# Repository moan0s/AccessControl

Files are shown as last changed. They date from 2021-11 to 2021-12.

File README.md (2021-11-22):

# AccessControl
To control asual key box with an ESP over the cloud in the fablab of my university. As a server ILMO (https://github.com/moan0s/ILMO) is used.
For the usage of the key tresor from wuerth it is neccesarry to modify it a bit. You have to remove the nose and replace it by the electromagnetic lock drawer. Also the locker pin at the door has to be replaced by the printed version.

The printed box covers the whole electronic stuff and also two LEDs and the RFID modul.

The circuit is made with fritzing. (https://fritzing.org/)
The 3d parts are made with Solid Works Student.

Bill of materials:
* RC552 (RFID Reader)
* ESP32
* Electromagnetic Lock Drawer (e.g. https://www.amazon.de/gp/product/B08G58WZDQ/ref=ppx_yo_dt_b_asin_title_o02_s00?ie=UTF8&psc=1)
* Key tresor (e.g. https://eshop.wuerth.de/Haengeschrank-zur-Schluesselaufbewahrung-SHSLSHRNK-METALL-22-SCHLUESSEL/0824010080.sku/de/DE/EUR/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)
* Some small electronic components (see Circuit diagram)
* M4 Screws, washers and nuts

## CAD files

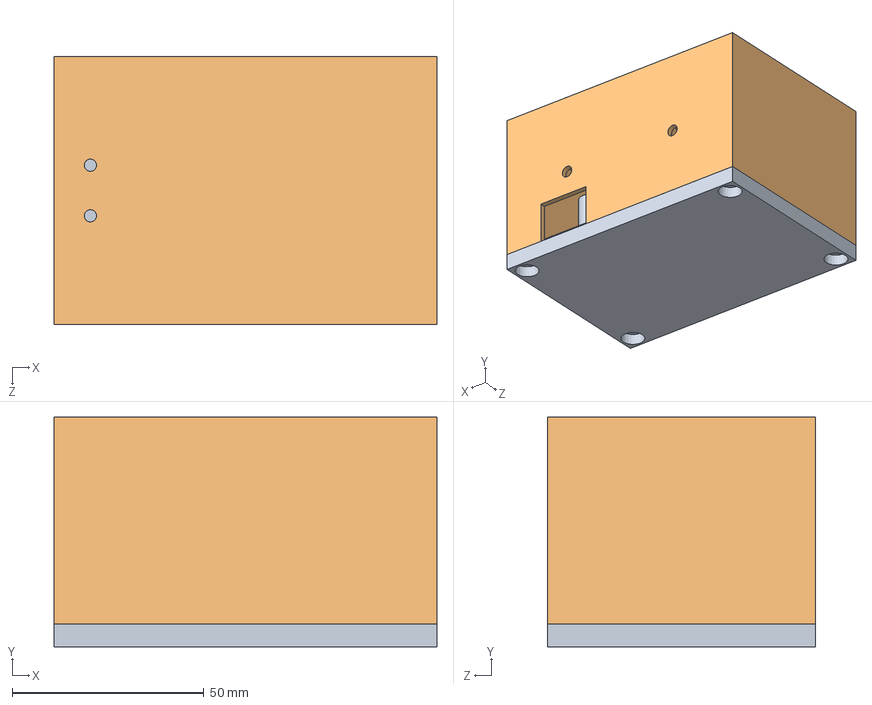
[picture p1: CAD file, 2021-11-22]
CAD/Solid Works/CaseComplete.SLDASM
100.0 x 60.0 x 70.0 mm
CaseTop
CaseBottom

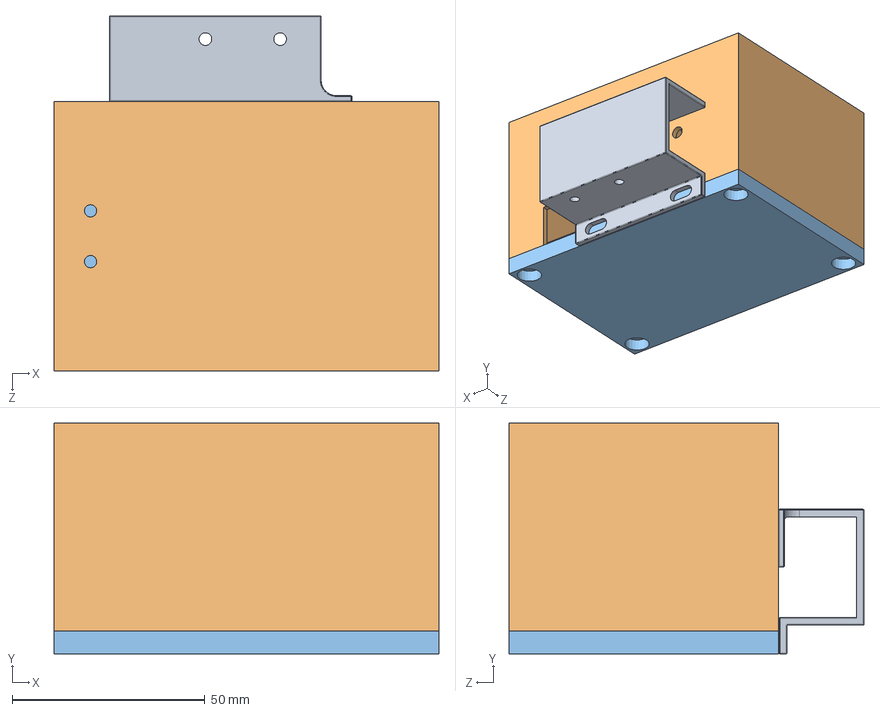
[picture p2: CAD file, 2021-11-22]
CAD/Solid Works/Complete.SLDASM
100.0 x 60.0 x 92.2 mm
DrawerHolder
CaseTop
CaseBottom

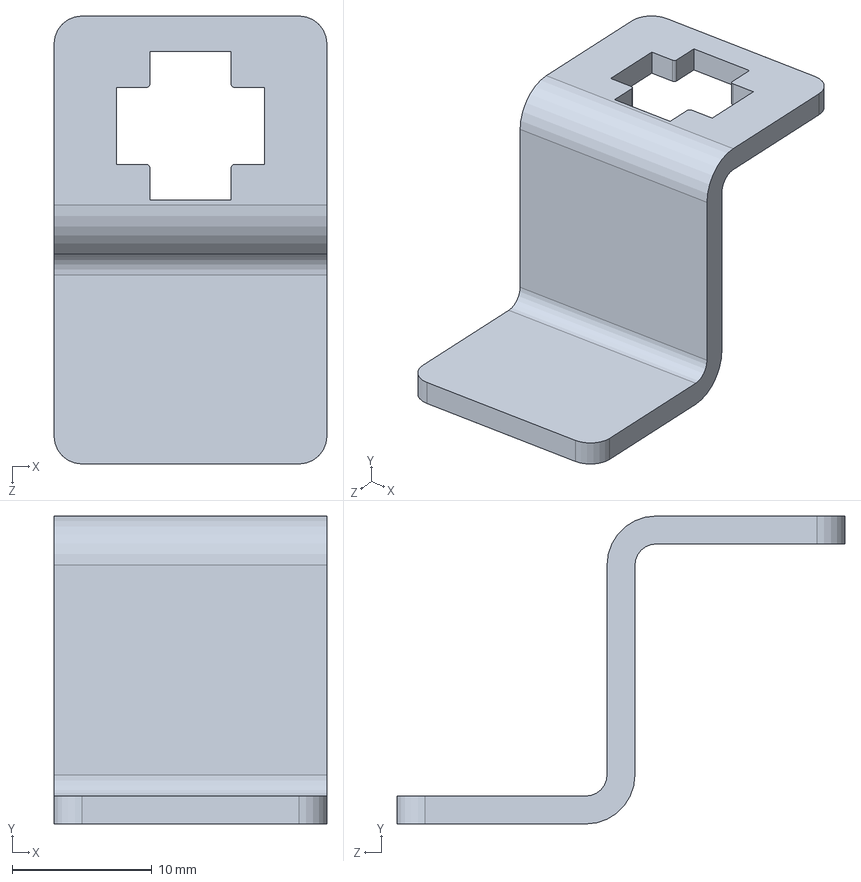
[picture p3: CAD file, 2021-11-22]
CAD/Solid Works/LockerPin.SLDPRT
19.5 x 22.0 x 32.0 mm

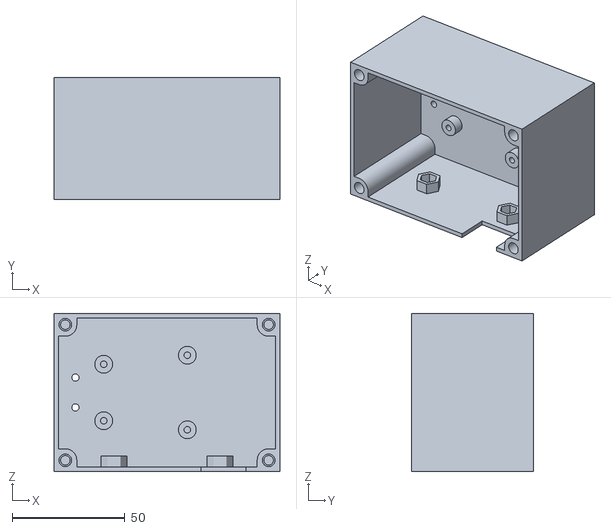
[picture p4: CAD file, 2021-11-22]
CAD/STL/CaseTop.STL
100.0 x 54.0 x 70.0

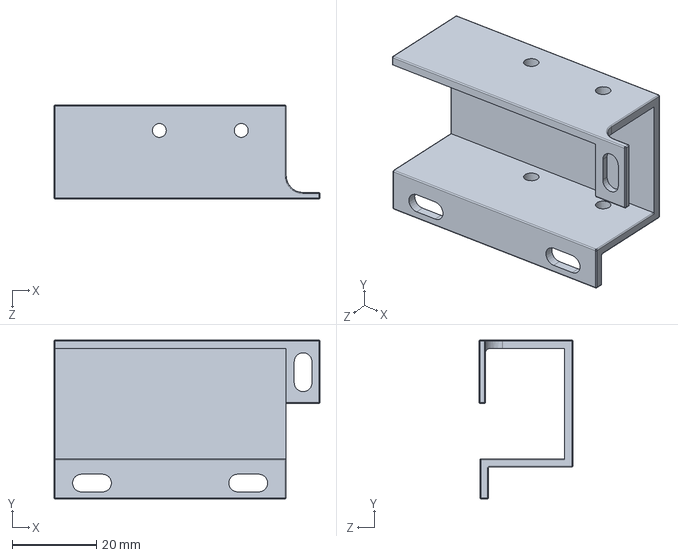
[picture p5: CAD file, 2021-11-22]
CAD/Solid Works/DrawerHolder.SLDPRT
63.0 x 37.6 x 22.2 mm

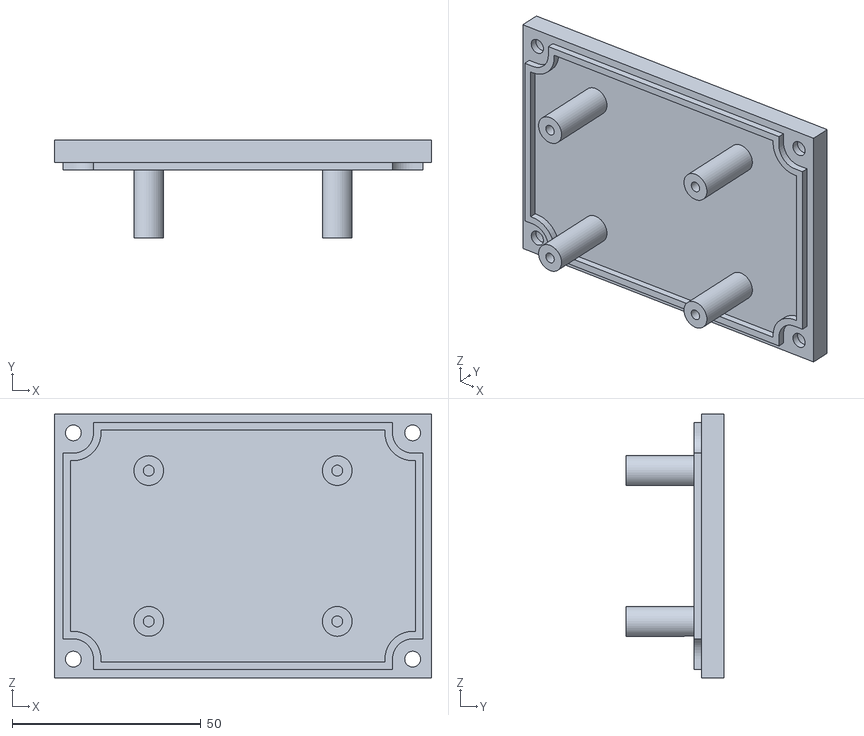
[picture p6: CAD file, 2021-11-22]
CAD/STL/CaseBottom.STL
100.0 x 26.0 x 70.0

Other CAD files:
CAD/STL/DrawerHolder.STL
CAD/Solid Works/CaseTop.SLDPRT
CAD/STL/LockerPin.STL
CAD/Solid Works/CaseBottom.SLDPRT

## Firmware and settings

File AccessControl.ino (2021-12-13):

#include <SPI.h>
#include <MFRC522.h>
#include <WiFiClientSecure.h>

#define RST_PIN         22         // Change to your configuration
#define SS_PIN          21         // Change to your configuration

#define LOCKER_PIN      13         //2: Built-In LED
#define GREEN_PIN       2
#define RED_PIN         15
#define BUZZER_PIN      34

#define LOCKER_TIME     2000      //In ms
#define BUZZER_TIME     5000      //In ms
#define BLINK_TIME      1000      //In ms

char* ssid     = "DEMO-WIFI";      // Change to your configuration
char* password = "16x7<Z82";       // Change to your configuration

const char* server = "www.fs-medtech.de";
char* path = "/bib_test/";  //Slash is necessary

const char* room_id = "";

String token = "123456";


//www.fs-medtech.de
const char* root_ca = \
                      "-----BEGIN CERTIFICATE-----\n" \
                      "MIIFazCCA1OgAwIBAgIRAIIQz7DSQONZRGPgu2OCiwAwDQYJKoZIhvcNAQELBQAw\n" \
                      "TzELMAkGA1UEBhMCVVMxKTAnBgNVBAoTIEludGVybmV0IFNlY3VyaXR5IFJlc2Vh\n" \
                      "cmNoIEdyb3VwMRUwEwYDVQQDEwxJU1JHIFJvb3QgWDEwHhcNMTUwNjA0MTEwNDM4\n" \
                      "WhcNMzUwNjA0MTEwNDM4WjBPMQswCQYDVQQGEwJVUzEpMCcGA1UEChMgSW50ZXJu\n" \
                      "ZXQgU2VjdXJpdHkgUmVzZWFyY2ggR3JvdXAxFTATBgNVBAMTDElTUkcgUm9vdCBY\n" \
                      "MTCCAiIwDQYJKoZIhvcNAQEBBQADggIPADCCAgoCggIBAK3oJHP0FDfzm54rVygc\n" \
                      "h77ct984kIxuPOZXoHj3dcKi/vVqbvYATyjb3miGbESTtrFj/RQSa78f0uoxmyF+\n" \
                      "0TM8ukj13Xnfs7j/EvEhmkvBioZxaUpmZmyPfjxwv60pIgbz5MDmgK7iS4+3mX6U\n" \
                      "A5/TR5d8mUgjU+g4rk8Kb4Mu0UlXjIB0ttov0DiNewNwIRt18jA8+o+u3dpjq+sW\n" \
                      "T8KOEUt+zwvo/7V3LvSye0rgTBIlDHCNAymg4VMk7BPZ7hm/ELNKjD+Jo2FR3qyH\n" \
                      "B5T0Y3HsLuJvW5iB4YlcNHlsdu87kGJ55tukmi8mxdAQ4Q7e2RCOFvu396j3x+UC\n" \
                      "B5iPNgiV5+I3lg02dZ77DnKxHZu8A/lJBdiB3QW0KtZB6awBdpUKD9jf1b0SHzUv\n" \
                      "KBds0pjBqAlkd25HN7rOrFleaJ1/ctaJxQZBKT5ZPt0m9STJEadao0xAH0ahmbWn\n" \
                      "OlFuhjuefXKnEgV4We0+UXgVCwOPjdAvBbI+e0ocS3MFEvzG6uBQE3xDk3SzynTn\n" \
                      "jh8BCNAw1FtxNrQHusEwMFxIt4I7mKZ9YIqioymCzLq9gwQbooMDQaHWBfEbwrbw\n" \
                      "qHyGO0aoSCqI3Haadr8faqU9GY/rOPNk3sgrDQoo//fb4hVC1CLQJ13hef4Y53CI\n" \
                      "rU7m2Ys6xt0nUW7/vGT1M0NPAgMBAAGjQjBAMA4GA1UdDwEB/wQEAwIBBjAPBgNV\n" \
                      "HRMBAf8EBTADAQH/MB0GA1UdDgQWBBR5tFnme7bl5AFzgAiIyBpY9umbbjANBgkq\n" \
                      "hkiG9w0BAQsFAAOCAgEAVR9YqbyyqFDQDLHYGmkgJykIrGF1XIpu+ILlaS/V9lZL\n" \
                      "ubhzEFnTIZd+50xx+7LSYK05qAvqFyFWhfFQDlnrzuBZ6brJFe+GnY+EgPbk6ZGQ\n" \
                      "3BebYhtF8GaV0nxvwuo77x/Py9auJ/GpsMiu/X1+mvoiBOv/2X/qkSsisRcOj/KK\n" \
                      "NFtY2PwByVS5uCbMiogziUwthDyC3+6WVwW6LLv3xLfHTjuCvjHIInNzktHCgKQ5\n" \
                      "ORAzI4JMPJ+GslWYHb4phowim57iaztXOoJwTdwJx4nLCgdNbOhdjsnvzqvHu7Ur\n" \
                      "TkXWStAmzOVyyghqpZXjFaH3pO3JLF+l+/+sKAIuvtd7u+Nxe5AW0wdeRlN8NwdC\n" \
                      "jNPElpzVmbUq4JUagEiuTDkHzsxHpFKVK7q4+63SM1N95R1NbdWhscdCb+ZAJzVc\n" \
                      "oyi3B43njTOQ5yOf+1CceWxG1bQVs5ZufpsMljq4Ui0/1lvh+wjChP4kqKOJ2qxq\n" \
                      "4RgqsahDYVvTH9w7jXbyLeiNdd8XM2w9U/t7y0Ff/9yi0GE44Za4rF2LN9d11TPA\n" \
                      "mRGunUHBcnWEvgJBQl9nJEiU0Zsnvgc/ubhPgXRR4Xq37Z0j4r7g1SgEEzwxA57d\n" \
                      "emyPxgcYxn/eR44/KJ4EBs+lVDR3veyJm+kXQ99b21/+jh5Xos1AnX5iItreGCc=\n" \
                      "-----END CERTIFICATE-----\n";

MFRC522 mfrc522(SS_PIN, RST_PIN);  // Create MFRC522 instance

WiFiClientSecure client;

void setup() {
  pinMode(LOCKER_PIN, OUTPUT);
  pinMode(GREEN_PIN, OUTPUT);
  pinMode(RED_PIN, OUTPUT);
  pinMode(BUZZER_PIN, OUTPUT);

  Serial.begin(115200);   // Initialize serial communications with the PC
  SPI.begin();            // Init SPI bus
  mfrc522.PCD_Init();     // Init MFRC522
  mfrc522.PCD_DumpVersionToSerial();  // Show details of PCD - MFRC522 Card Reader details
  WiFi.begin(ssid, password);
  Serial.println("Connecting");
  digitalWrite(RED_PIN, HIGH);
  while (WiFi.status() != WL_CONNECTED) {
    //WiFi.begin(ssid, password);
    delay(1000);
    Serial.print(".");
  }

  Serial.print("Connected to ");
  Serial.println(ssid);
  digitalWrite(RED_PIN, LOW);

  client.setCACert(root_ca);
}

void loop()
{
  // Look for new cards
  if ( ! mfrc522.PICC_IsNewCardPresent())
  {
    return;
  }

  // Select one of the cards
  if ( ! mfrc522.PICC_ReadCardSerial()) {
    return;
  }

  if (WiFi.status() == WL_CONNECTED) {
    String content = "";
    byte letter;
    for (byte i = 0; i < mfrc522.uid.size; i++)
    {
      content.concat(String(mfrc522.uid.uidByte[i] < 0x10 ? " 0" : " "));
      content.concat(String(mfrc522.uid.uidByte[i], HEX));
    }
    content.toUpperCase();
    String cardnumber = content.substring(1);
    cardnumber.replace(" ", "");  //Remove spaces
    Serial.println(cardnumber);

    digitalWrite(RED_PIN, HIGH);
    digitalWrite(GREEN_PIN, HIGH);
    Serial.println("\nStarting connection to server...");
    if (!client.connect(server, 443))
      Serial.println("Connection failed!");
    else {
      Serial.println("Connected to server!");
      // Make a HTTP request:
      String httpRequestData = "library/api/uid/"+ cardnumber + "/room/" + room_id;
      Serial.println("https://" + String(server) + String(path) + httpRequestData);
      client.println("GET https://" + String(server) + String(path) + httpRequestData + " HTTP/1.1");
      client.println("Authorization: Token "+token);
      client.println("Host:" + String(server));
      client.println("Connection: close");
      client.println();
      digitalWrite(RED_PIN, LOW);
      digitalWrite(GREEN_PIN, LOW);

      String responseCode = getResponseCode();
      Serial.print("Response Code: ");
      Serial.println(responseCode);
      client.stop();

      if (responseCode == "200") {    //Access
        Serial.println("Access");
        digitalWrite(GREEN_PIN, HIGH);
        digitalWrite(LOCKER_PIN, HIGH);
        delay(LOCKER_TIME);
        digitalWrite(LOCKER_PIN, LOW);
        digitalWrite(GREEN_PIN, LOW);
      }
      else if (responseCode == "401") { //No access
        Serial.println("No Access");
        digitalWrite(BUZZER_PIN, HIGH);
        for (int i = 0; i <= round(BUZZER_TIME / (BLINK_TIME * 2)); i++) {
          digitalWrite(RED_PIN, HIGH);
          delay(BLINK_TIME);
          digitalWrite(RED_PIN, LOW);
          delay(BLINK_TIME);
        }
        digitalWrite(BUZZER_PIN, LOW);
      }
      else { //Error, try again
        digitalWrite(RED_PIN, HIGH);
        delay(BUZZER_TIME);
        digitalWrite(RED_PIN, LOW);
      }
    }
  }
}

String getResponseCode() {
  String responseCode = "";
  int abc = 0;
  while (client.connected()) {
    if (client.available()) {
      String response = client.readStringUntil('\n');
      abc++;
        if (abc >= 20 && abc <= 30) {
          responseCode = response.substring(0, 3);
          if (responseCode.toInt() != 0) { //If response code is a number
             return responseCode;          //Valid number found
          }
        }
      }
  }
  return "0"; // No valid number found
}

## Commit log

2021-09-23 Remove Serial.println()
2021-10-22 Adding Support for HTTPS and change to ESP32
2021-10-22 Add check http response code
    With workaround because ILMO returns actuallay everytime 200. Now line 25 of the response contains the http response code
    [AccessControl.ino]
2021-10-28 Access logic and output added
    Added logic based on http Code; LED, buzzer and locker output added;
    [AccessControl.ino]
2021-11-04 Change locker pin
2021-11-22 Changing pin layout to schema
2021-11-22 Adding BOM and short description
2021-11-22 Adding Solid Works files
    [CaseBottom.SLDPRT, CaseComplete.SLDASM, CaseTop.SLDPRT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]
2021-11-22 Adding STL files
    [CaseBottom.STL, CaseTop.STL, DrawerHolder.STL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]
2021-12-13 Change to support ILMO2
    https://github.com/moan0s/ILMO2/issues/25
    [AccessControl.ino]
